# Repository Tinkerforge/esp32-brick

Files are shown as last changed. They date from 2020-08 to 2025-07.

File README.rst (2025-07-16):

ESP32 Brick
===========

This repository contains the firmware source code and the hardware design
files. The documentation generator configs can be found at
https://github.com/Tinkerforge/generators

Repository Overview
-------------------

.. DO NOT EDIT THIS OVERVIEW MANUALLY! CHANGE https://github.com/Tinkerforge/esp32-firmware/repo_overview.rst AND COPY THAT BLOCK INTO ALL REPOS LISTED BELOW. TODO: AUTOMATE THIS

Software
~~~~~~~~
- `esp32-firmware <https://github.com/Tinkerforge/esp32-firmware>`__  **Please report any issues concerning WARP hard- and software here!** Source code of the ESP32 firmware shared between all WARP Chargers and Energy Managers

- `tfjson <https://github.com/Tinkerforge/tfjson>`__ SAX style JSON serializer and deserializer
- `tfmodbustcp <https://github.com/Tinkerforge/tfmodbustcp>`__ Modbus TCP server and client implementation
- `tfocpp <https://github.com/Tinkerforge/tfocpp>`__ OCPP 1.6 implementation
- `tftools <https://github.com/Tinkerforge/tftools>`__ Miscellaneous tools and helpers

- `esp32-remote-access <https://github.com/Tinkerforge/esp32-remote-access>`__ Source code of the my.warp-charger.com remote access server

- `warp-charger <https://github.com/Tinkerforge/warp-charger>`__ The source code of (docs.)warp-charger.com and the printed manual, released firmwares, datasheets and documents, as well as some tools and hardware design files
- `api.warp-charger.com <https://github.com/Tinkerforge/api.warp-charger.com>`__ Serves APIs that are used by WARP Chargers to obtain relevant public information like day ahead prices
- `vislog.warp-charger.com <https://github.com/Tinkerforge/vislog.warp-charger.com>`__ Visualizes WARP Charger logs and EVSE debug protocols
- `dbus-warp-charger <https://github.com/Tinkerforge/dbus-warp-charger>`__ Integrates WARP Chargers into a Victron Energy Venus OS device (e.g. Cerbo GX)

WARP Charger Hardware
~~~~~~~~~~~~~~~~~~~~~~

- `esp32-brick <https://github.com/Tinkerforge/esp32-brick>`__ Hardware design files of the ESP32 Brick
- `evse-bricklet <https://github.com/Tinkerforge/evse-bricklet>`__  Firmware source code and hardware design files of the EVSE Bricklet
- `rs485-bricklet <https://github.com/Tinkerforge/rs485-bricklet>`__ Firmware source code and hardware design files of the RS485 Bricklet

WARP2 Charger Hardware
~~~~~~~~~~~~~~~~~~~~~~

- `esp32-ethernet-brick <https://github.com/Tinkerforge/esp32-ethernet-brick>`__ Hardware design files of the ESP32 Ethernet Brick
- `evse-v2-bricklet <https://github.com/Tinkerforge/evse-v2-bricklet>`__ Firmware source code and hardware design files of the EVSE 2.0 Bricklet
- `nfc-bricklet <https://github.com/Tinkerforge/nfc-bricklet>`__ Firmware source code and hardware design files of the NFC Bricklet

WARP3 Charger Hardware
~~~~~~~~~~~~~~~~~~~~~~

- `warp-esp32-ethernet-brick <https://github.com/Tinkerforge/warp-esp32-ethernet-brick>`__ Hardware design files of the WARP ESP32 Ethernet Brick
- `evse-v3-bricklet <https://github.com/Tinkerforge/evse-v3-bricklet>`__ Firmware source code and hardware design files of the EVSE 3.0 Bricklet
- `nfc-bricklet <https://github.com/Tinkerforge/nfc-bricklet>`__ Firmware source code and hardware design files of the NFC Bricklet

WARP Energy Manager Hardware
~~~~~~~~~~~~~~~~~~~~~~~~~~~~

- `esp32-ethernet-brick <https://github.com/Tinkerforge/esp32-ethernet-brick>`__ Hardware design files of the ESP32 Ethernet Brick
- `warp-energy-manager-bricklet <https://github.com/Tinkerforge/warp-energy-manager-bricklet>`__ Firmware source code and hardware design files of the WARP Energy Manager Bricklet

WARP Energy Manager 2.0 Hardware
~~~~~~~~~~~~~~~~~~~~~~~~~~~~~~~~

- `esp32-ethernet-brick <https://github.com/Tinkerforge/esp32-ethernet-brick>`__ Hardware design files of the ESP32 Ethernet Brick
- `warp-energy-manager-v2-bricklet <https://github.com/Tinkerforge/warp-energy-manager-v2-bricklet>`__ Firmware source code and hardware design files of the WARP Energy Manager 2.0 Bricklet
- `warp-front-panel-bricklet <https://github.com/Tinkerforge/warp-front-panel-bricklet>`__ Firmware source code and hardware design files of the WARP Front Panel Bricklet

Forked/patched projects
~~~~~~~~~~~~~~~~~~~~~~~

- `arduino-esp32 <https://github.com/Tinkerforge/arduino-esp32>`__
- `esp32-arduino-libs <https://github.com/Tinkerforge/esp32-arduino-libs>`__
- `WireGuard-ESP32-Arduino <https://github.com/Tinkerforge/WireGuard-ESP32-Arduino>`__

Repository Content
------------------

software/:
 * examples/: Examples for all supported languages
 * build/: Compiled files
 * src/: Source code of firmware
 * Makefile: Makefile to build project

hardware/:
 * Contains KiCad project files and additionally schematics as PDF

datasheets/:
 * Contains datasheets for sensors and complex ICs that are used

Hardware
--------

The hardware is designed with the open source EDA Suite KiCad
(http://www.kicad.org). Before you are able to open the files,
you have to install the Tinkerforge kicad-libraries
(https://github.com/Tinkerforge/kicad-libraries). You can either clone
them directly in hardware/ or clone them in a separate folder and
symlink them into hardware/
(ln -s kicad_path/kicad-libraries project_path/hardware). After that you
can open the .pro file in hardware/ with KiCad and from there view and
modify the schematics and the PCB layout.

Software
--------

See README.txt in the software folder for details.

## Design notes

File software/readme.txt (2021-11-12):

The content of this directory was merged into

https://github.com/Tinkerforge/esp32-firmware/tree/master/software

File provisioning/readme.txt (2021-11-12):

The content of this directory was moved to

https://github.com/Tinkerforge/esp32-firmware/tree/master/provisioning

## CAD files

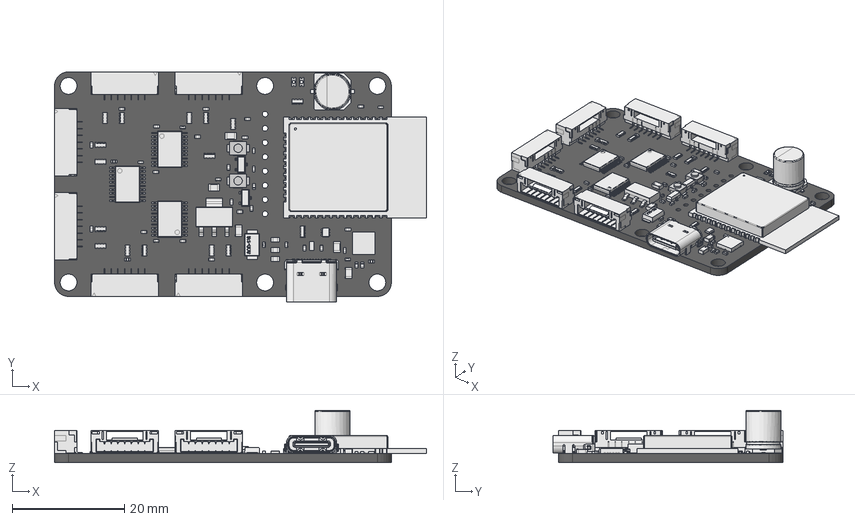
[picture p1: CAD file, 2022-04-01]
hardware/esp32.FCStd
66.2 x 41.0 x 9.30 mm
Pcb_7dfd
ESP32-WROOM-32
ESP32-WROOM-033
ESP32-WROOM-034
ESP32-WROOM-035
ESP32-WROOM-036
ESP32-WROOM-037
ESP32-WROOM-038
ESP32-WROOM-039
ESP32-WROOM-040
ESP32-WROOM-041
ESP32-WROOM-042
ESP32-WROOM-043
ESP32-WROOM-044
ESP32-WROOM-045
ESP32-WROOM-046
ESP32-WROOM-047
ESP32-WROOM-048
ESP32-WROOM-049
ESP32-WROOM-050
ESP32-WROOM-051
ESP32-WROOM-052
ESP32-WROOM-053
ESP32-WROOM-054
ESP32-WROOM-055
ESP32-WROOM-056
ESP32-WROOM-057
ESP32-WROOM-058
ESP32-WROOM-059
ESP32-WROOM-060
ESP32-WROOM-061
ESP32-WROOM-062
ESP32-WROOM-063
ESP32-WROOM-064
ESP32-WROOM-065
ESP32-WROOM-066
ESP32-WROOM-067
ESP32-WROOM-068
ESP32-WROOM-069
ESP32-WROOM-070
ESP32-WROOM-071
ESP32-WROOM-072
C112_C_0805_5F5B4DA2 x 5
SW101_B3U_1000P[]_5F5B68B4 x 2
Q102_SOT23_5E999EC0 x 2
RP104_Cut_5E9D7D33 x 16
U203_TSSOP-20_5E99A0A3 x 3
R202_R_0402_5E999F6A x 26
P206_BrickletConn_7pin_5E9D989A x 6
L104_R_0603_5E999E38 x 3
USB4105
USB4106
U103_QFN-24_4x4mm_Pitch0.5mm_5E99F04F
C101_C_0402_5E99F739 x 11
c_el_D8_D63_L77

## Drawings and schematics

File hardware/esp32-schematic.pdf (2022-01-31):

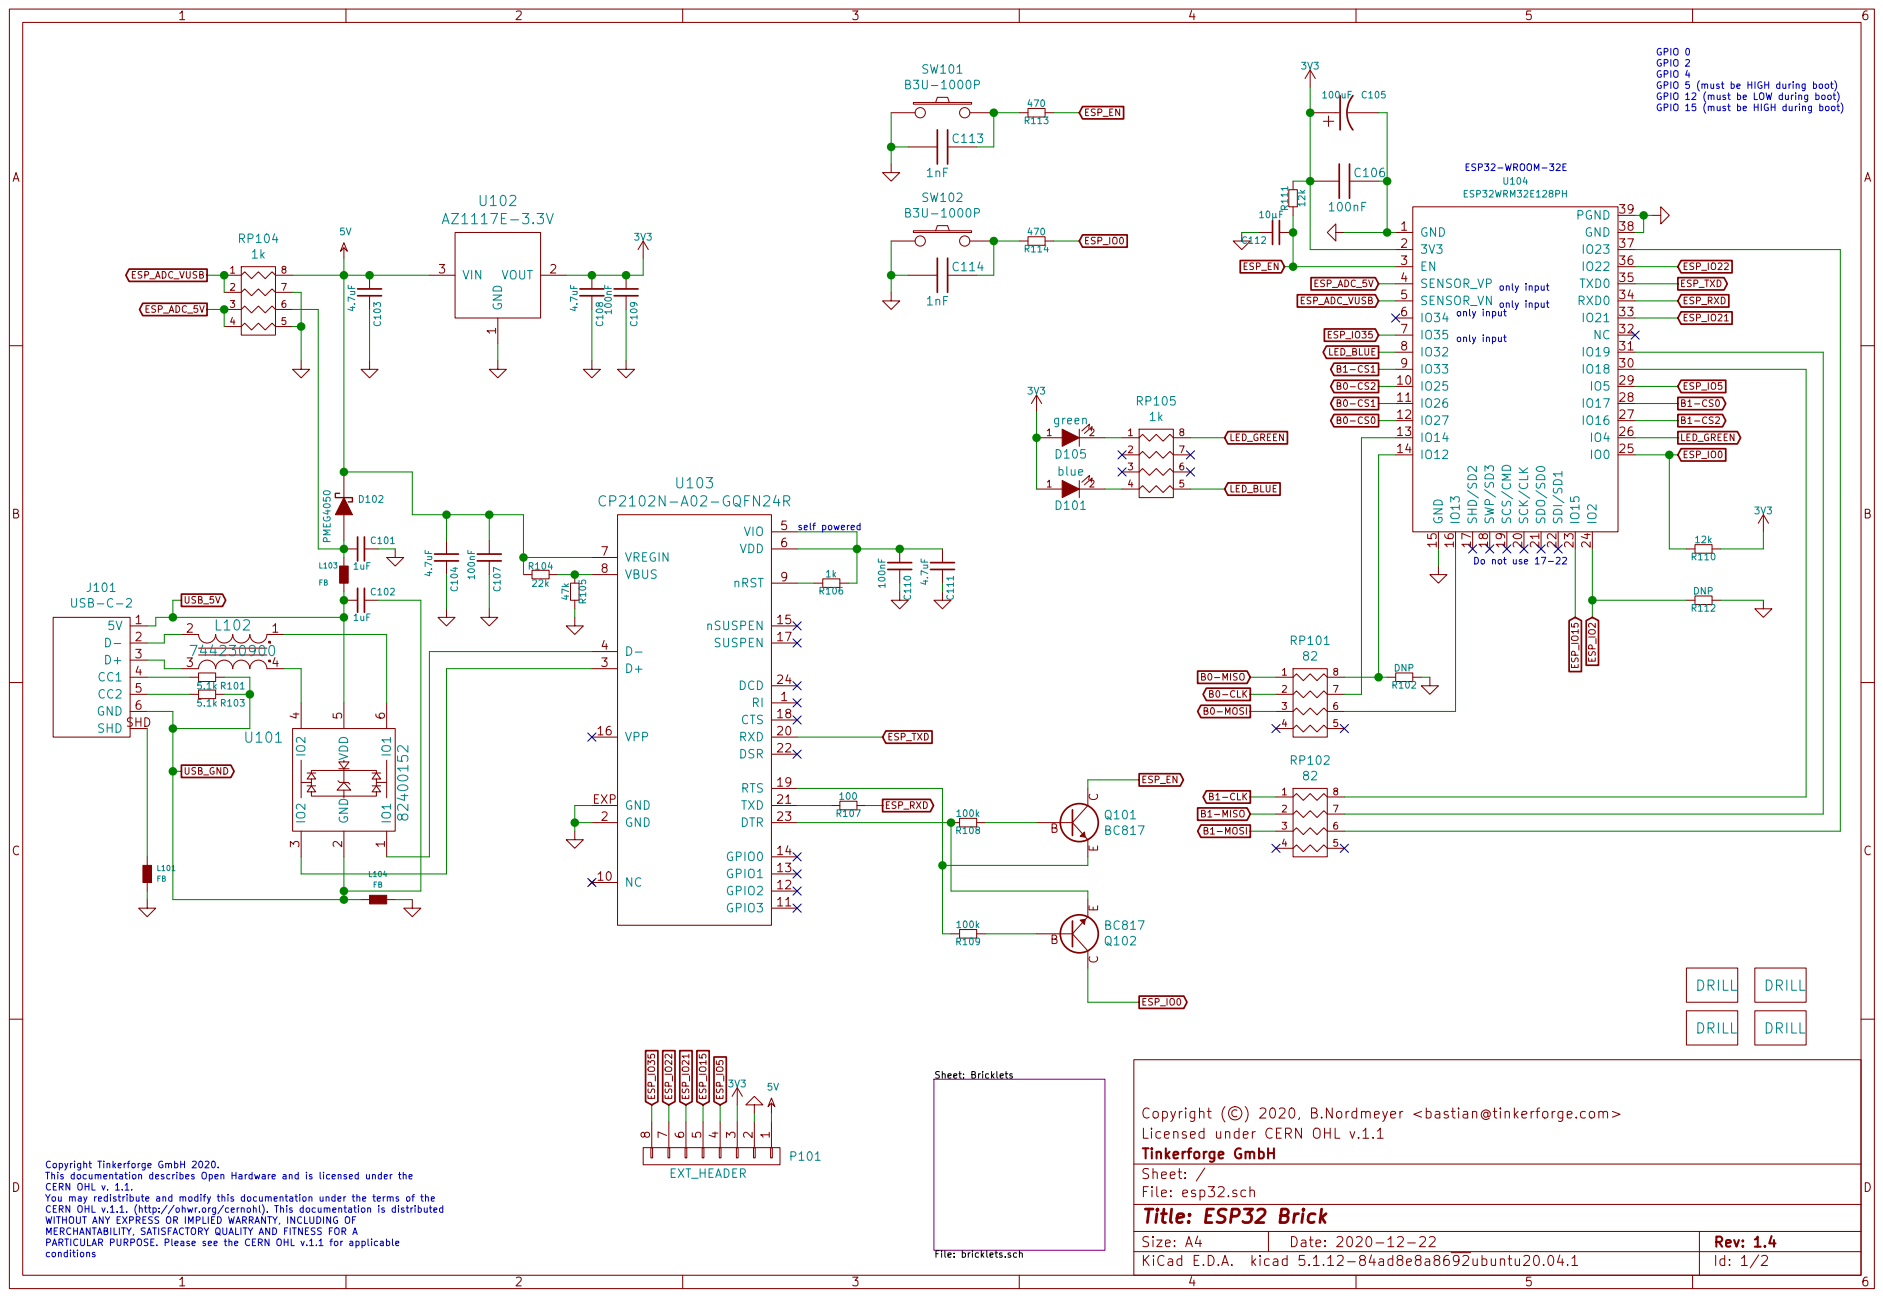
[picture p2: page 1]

GPIO 0
GPIO 2
GPIO 4
GPIO 5 (must be HIGH during boot)
GPIO 12 (must be LOW during boot)

GPIO 15 (must be HIGH during boot) only input only input only input only input Do not use 17-22 ESP32-WROOM-32E

self powered Copyright Tinkerforge GmbH 2020. This documentation describes Open Hardware and is licensed under the CERN OHL v. 1.1. You may redistribute and modify this documentation under the terms of the CERN OHL v.1.1. (http://ohwr.org/cernohl). This documentation is distributed WITHOUT ANY EXPRESS OR IMPLIED WARRANTY, INCLUDING OF MERCHANTABILITY, SATISFACTORY QUALITY AND FITNESS FOR A

Sheet: Bricklets File: bricklets.sch

Licensed under CERN OHL v.1.1 Copyright (©) 2020, B.Nordmeyer <bastian@tinkerforge.com>

File: esp32.sch Sheet: / Tinkerforge GmbH

PARTICULAR PURPOSE. Please see the CERN OHL v.1.1 for applicable
conditions

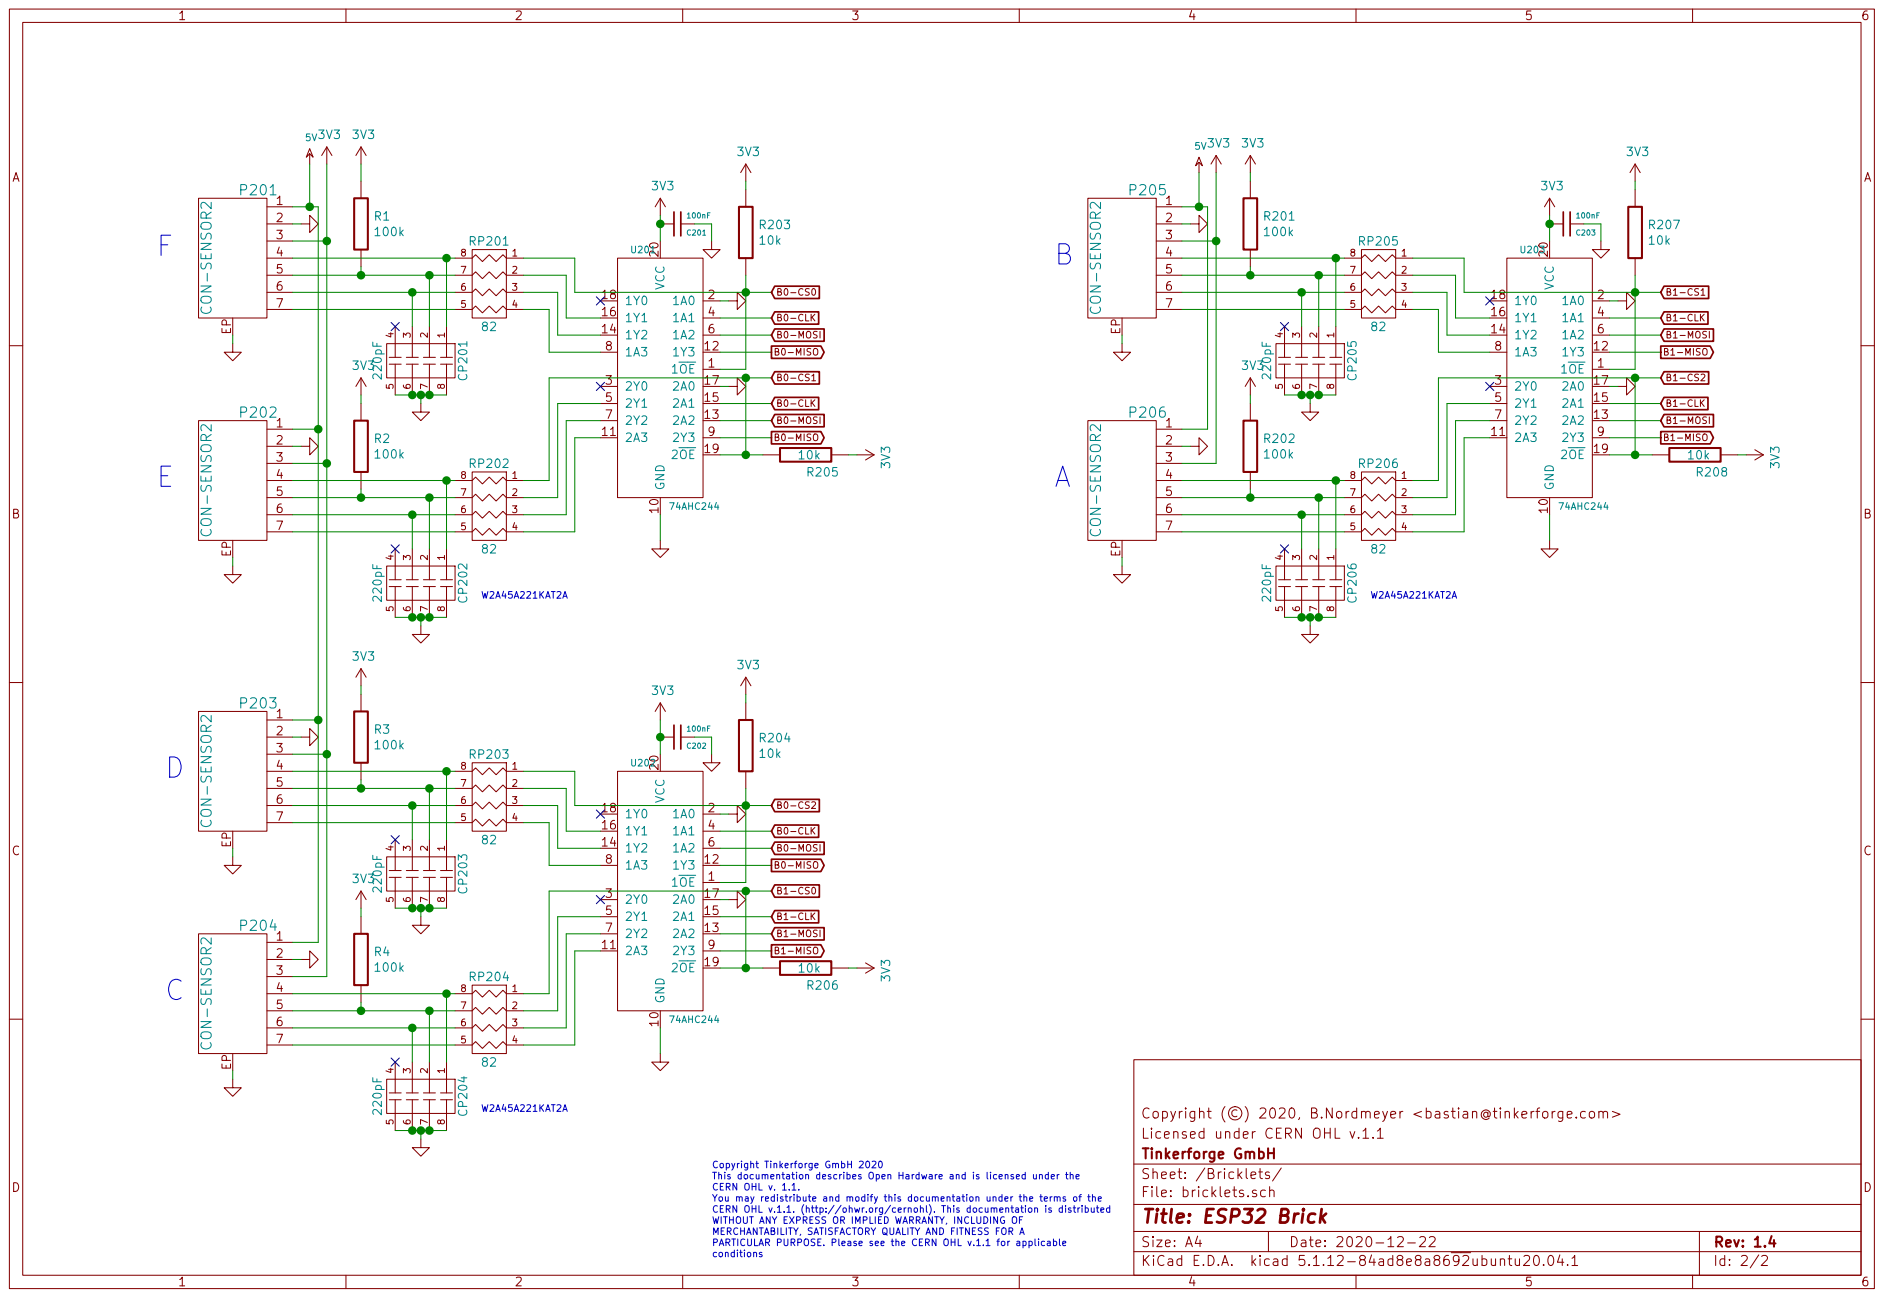
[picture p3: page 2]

Licensed under CERN OHL v.1.1 Copyright (©) 2020, B.Nordmeyer <bastian@tinkerforge.com> R4

File: bricklets.sch Sheet: /Bricklets/ Tinkerforge GmbH

PARTICULAR PURPOSE. Please see the CERN OHL v.1.1 for applicable

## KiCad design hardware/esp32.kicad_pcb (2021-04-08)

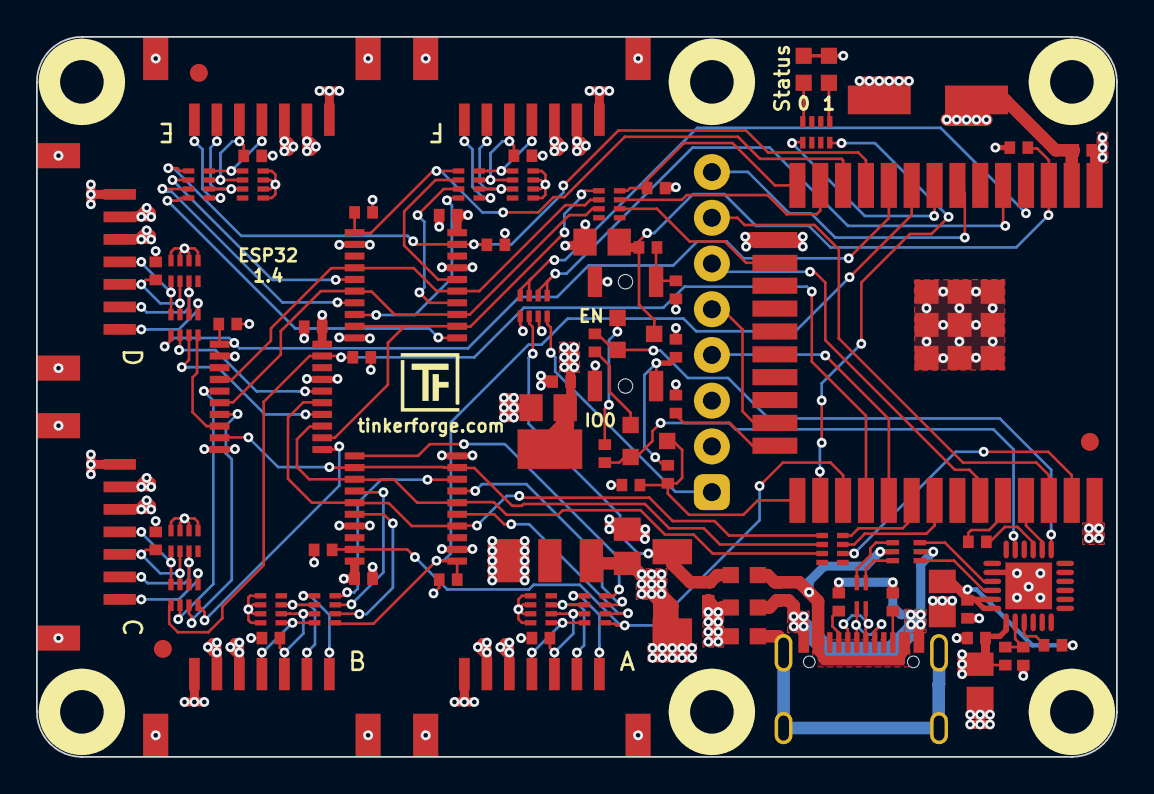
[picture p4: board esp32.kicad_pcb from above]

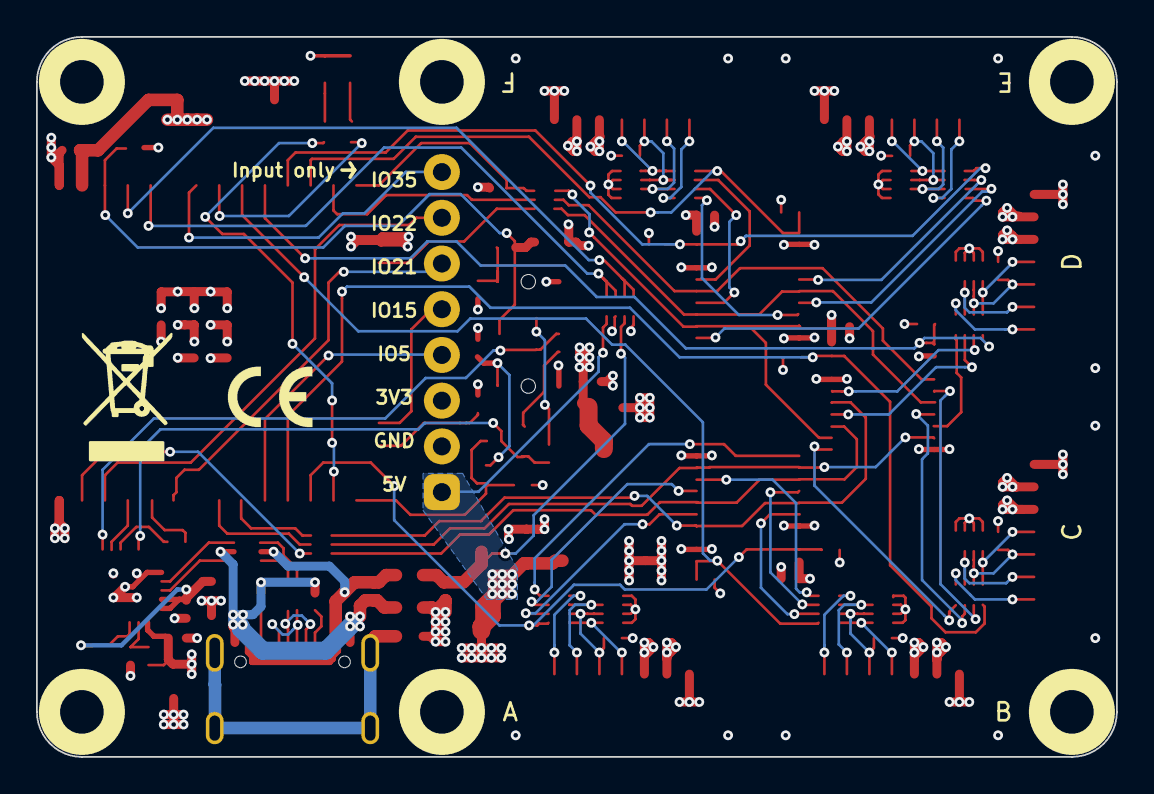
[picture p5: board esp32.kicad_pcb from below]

Board: 4 copper layers, 60.0 x 40.0 mm, 94 parts (2 on the bottom side), 101 nets.

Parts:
C101, C102: 1uF; C0402F
C103, C104, C108, C111: 4.7uF; C0805E
C105: 100uF; ELKO_63
C106, C107, C109, C110, C201, C202, C203: 100nF; C0402F
C112: 10µF; C0805E
C113, C114: 1nF; C0402F
CP201, CP202, CP203, CP204, CP205, CP206: 220pF; 4X0402
D101: blue; D0603F
D102: PMEG4050; SOD-128
D105: green; D0603F
F101, F102, F103, F104: DRILL; DRILL_NP
Fiducial_Mark: VAL**; Fiducial_Mark
Fiducial_Mark#2, Fiducial_Mark#3: VAL**; Fiducial_Mark
J101: USB-C-2
L101, L103, L104: FB; R0603F
L102: 744230900; WE-CNSW-0603
P101: EXT_HEADER; pin_array_1x8-P2mm_D1mm
P201, P202, P203, P204, P205, P206: CON-SENSOR2
Q101, Q102: BC817; SOT23EBC
R1, R2, R3, R4, R108, R109, R201, R202: 100k; R0402F
R101, R103: 5.1k; R0402F
R102, R112: DNP; R0402F
R104: 22k; R0402F
R105: 47k; R0402F
R106: 1k; R0402F
R107: 100; R0402F
R110, R111: 12k; R0402F
R113, R114: 470; R0402F
R203, R204, R205, R206, R207, R208: 10k; R0402F
RP101, RP102, RP201, RP202, RP203, RP204, RP205, RP206: 82; 4X0402
RP104, RP105: 1k; 4X0402
SW101, SW102: B3U-1000P
U101: 82400152; SOT563-SPEC
U102: AZ1117E-3.3V; SOT-223
U103: CP2102N-A02-GQFN24R; QFN24-4x4mm-0.5mm
U104: ESP32WRM32E128PH; ESP32-WROOM-32
U201, U202, U203: 74AHC244; TSSOP20
VAL: WEEE_7mm
VAL#2: CE_5mm

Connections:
3V3: C105.1, C106.2, C108.2, C109.2, C201.2, C202.2, C203.2, D101.1, D105.1, P101.3, P201.3, P202.3, P203.3, P204.3, P205.3, P206.3, R1.1, R2.1, R3.1, R4.1, R110.2, R111.1, R201.1, R202.1, R203.1, R204.1, R205.1, R206.1, R207.1, R208.1, U102.2, U104.2, U201.20, U202.20, U203.20
5V: C103.2, C104.2, C107.2, D102.2, P101.1, P201.1, P202.1, P203.1, P204.1, P205.1, P206.1, R104.2, RP104.8, U102.3, U103.7
B0-CLK: RP101.2, U201.4, U201.15, U202.4
B0-CS0: R203.2, RP201.1, U104.12, U201.1
B0-CS1: R205.2, RP202.1, U104.11, U201.19
B0-CS2: R204.2, RP203.1, U104.10, U202.1
B0-MISO: RP101.1, U201.9, U201.12, U202.12
B0-MOSI: RP101.3, U201.6, U201.13, U202.6
B1-CLK: RP102.1, U202.15, U203.4, U203.15
B1-CS0: R206.2, RP204.1, U104.28, U202.19
B1-CS1: R207.2, RP205.1, U104.9, U203.1
B1-CS2: R208.2, RP206.1, U104.27, U203.19
B1-MISO: RP102.2, U202.9, U203.9, U203.12
B1-MOSI: RP102.3, U202.13, U203.6, U203.13
ESP_ADC_5V: RP104.3, RP104.4, U104.4
ESP_ADC_VUSB: RP104.1, RP104.2, U104.5
ESP_EN: C112.2, Q101.C, R111.2, R113.2, U104.3
ESP_IO0: Q102.C, R110.1, R114.2, U104.25
ESP_IO2: R112.1, U104.24
ESP_IO5: P101.4, U104.29
ESP_IO15: P101.5, U104.23
ESP_IO21: P101.6, U104.33
ESP_IO22: P101.7, U104.36
ESP_IO35: P101.8, U104.7
ESP_RXD: R107.2, U104.34
ESP_TXD: U103.20, U104.35
GND: C101.1, C103.1, C104.1, C105.2, C106.1, C107.1, C108.1, C109.1, C110.1, C111.1, C112.1, C113.2, C114.2, C201.1, C202.1, C203.1, CP201.5, CP201.6, CP201.7, CP201.8, CP202.5, CP202.6, CP202.7, CP202.8, CP203.5, CP203.6, CP203.7, CP203.8, CP204.5, CP204.6, CP204.7, CP204.8, CP205.5, CP205.6, CP205.7, CP205.8, CP206.5, CP206.6, CP206.7, CP206.8, L101.1, L104.2, P101.2, P201.2, P201.EP, P202.2, P202.EP, P203.2, P203.EP, P204.2, P204.EP, P205.2, P205.EP, P206.2, P206.EP, R102.2, R105.1, R112.2, RP104.5, RP104.7, SW101.1, SW102.1, U102.1, U103.2, U103.EXP, U104.1, U104.15, U104.38, U104.39, U201.2, U201.10, U201.17, U202.2, U202.10, U202.17, U203.2, U203.10, U203.17
LED_BLUE: RP105.5, U104.8
LED_GREEN: RP105.8, U104.26
unnamed: C101.2, D102.1, L103.2, RP104.6
unnamed: C110.2, C111.2, R106.2, U103.5, U103.6
unnamed: C113.1, R113.1, SW101.2
unnamed: C114.1, R114.1, SW102.2
unnamed: CP201.1, P201.4, RP201.8
unnamed: CP201.2, P201.5, R1.2, RP201.7
unnamed: CP201.3, P201.6, RP201.6
unnamed: CP202.1, P202.4, RP202.8
unnamed: CP202.2, P202.5, R2.2, RP202.7
unnamed: CP202.3, P202.6, RP202.6
unnamed: CP203.1, P203.4, RP203.8
unnamed: CP203.2, P203.5, R3.2, RP203.7
unnamed: CP203.3, P203.6, RP203.6
unnamed: CP204.1, P204.4, RP204.8
unnamed: CP204.2, P204.5, R4.2, RP204.7
unnamed: CP204.3, P204.6, RP204.6
unnamed: CP205.1, P205.4, RP205.8
unnamed: CP205.2, P205.5, R201.2, RP205.7
unnamed: CP205.3, P205.6, RP205.6
unnamed: CP206.1, P206.4, RP206.8
unnamed: CP206.2, P206.5, R202.2, RP206.7
unnamed: CP206.3, P206.6, RP206.6
unnamed: D101.2, RP105.4
unnamed: D105.2, RP105.1
unnamed: J101.2, L102.2
unnamed: J101.3, L102.3
unnamed: J101.4, R101.2
unnamed: J101.5, R103.2
unnamed: J101.SHD, L101.2
unnamed: L102.1, U101.6
unnamed: L102.4, U101.4
unnamed: P201.7, RP201.5
unnamed: P202.7, RP202.5
unnamed: P203.7, RP203.5
unnamed: P204.7, RP204.5
unnamed: P205.7, RP205.5
unnamed: P206.7, RP206.5
unnamed: Q101.B, R108.2
unnamed: Q101.E, R109.1, U103.19
unnamed: Q102.B, R109.2
unnamed: Q102.E, R108.1, U103.23
unnamed: R102.1, RP101.8, U104.14
unnamed: R104.1, R105.2, U103.8
unnamed: R106.1, U103.9
unnamed: R107.1, U103.21
unnamed: RP101.6, U104.16
unnamed: RP101.7, U104.13
unnamed: RP102.6, U104.37
unnamed: RP102.7, U104.31
unnamed: RP102.8, U104.30
unnamed: RP201.2, U201.16
unnamed: RP201.3, U201.14
unnamed: RP201.4, U201.8
unnamed: RP202.2, U201.5
unnamed: RP202.3, U201.7
unnamed: RP202.4, U201.11
unnamed: RP203.2, U202.16
unnamed: RP203.3, U202.14
unnamed: RP203.4, U202.8
unnamed: RP204.2, U202.5
unnamed: RP204.3, U202.7
unnamed: RP204.4, U202.11
unnamed: RP205.2, U203.16
unnamed: RP205.3, U203.14
unnamed: RP205.4, U203.8
unnamed: RP206.2, U203.5
unnamed: RP206.3, U203.7
unnamed: RP206.4, U203.11
unnamed: U101.1, U103.4
unnamed: U101.3, U103.3
USB_5V: C102.2, J101.1, L103.1, U101.5
USB_GND: C102.1, J101.6, L104.1, R101.1, R103.1, U101.2

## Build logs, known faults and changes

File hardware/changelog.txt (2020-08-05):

Version 1.1: Add extension header, fix NPN bug, change LED signals
Version 1.0: Initial

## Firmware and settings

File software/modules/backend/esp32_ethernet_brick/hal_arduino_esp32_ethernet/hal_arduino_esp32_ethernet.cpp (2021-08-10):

/*
 * Copyright (C) 2020 Erik Fleckstein <erik@tinkerforge.com>
 *
 * Redistribution and use in source and binary forms of this file,
 * with or without modification, are permitted. See the Creative
 * Commons Zero (CC0 1.0) License for more details.
 */

#include "hal_arduino_esp32_ethernet.h"
#include "SPI.h"
#include <Arduino.h>

#include "bindings/config.h"
#include "bindings/errors.h"

static const int CS_PIN_0 = 12;
static const int CS_PIN_1 = 13;
static const int CS_PIN_2 = 14;
static const int CLK_PIN = 32;
static const int MOSI_PIN = 33;
static const int MISO_PIN = 35;

void select_demux(uint8_t port_id) {
    // As we always alternate between select_demux and deselect_demux, we can assume, that all three pins are high.
    // clearing the pins we want to set to 0 is sufficient.

    //invert to use the W1TC (write 1 to clear) register
    uint8_t inv = ~port_id;
    REG_WRITE(GPIO_OUT_W1TC_REG, (inv & 0x07) << CS_PIN_0);
}

void deselect_demux() {
    REG_WRITE(GPIO_OUT_W1TS_REG, 0x07 << CS_PIN_0);
}

int tf_hal_create(TF_HalContext *hal, TF_Port *ports, uint8_t port_count) {
    int rc = tf_hal_common_create(hal);
    if (rc != TF_E_OK) {
        return rc;
    }

    hal->ports = ports;
    hal->port_count = port_count;

    hal->spi_settings = SPISettings(1400000, SPI_MSBFIRST, SPI_MODE3);

    hal->hspi = SPIClass(HSPI);
    hal->hspi.begin(CLK_PIN, MISO_PIN, MOSI_PIN);

    pinMode(CS_PIN_0, OUTPUT);
    pinMode(CS_PIN_1, OUTPUT);
    pinMode(CS_PIN_2, OUTPUT);
    deselect_demux();

    return tf_hal_common_prepare(hal, port_count, 50000);
}

int tf_hal_destroy(TF_HalContext *hal){
    hal->hspi.end();
    return TF_E_OK;
}

int tf_hal_chip_select(TF_HalContext *hal, uint8_t port_id, bool enable){
    if (enable) {
        hal->hspi.beginTransaction(hal->spi_settings);
        select_demux(port_id);
    } else {
        deselect_demux();
        hal->hspi.endTransaction();
    }
    return TF_E_OK;
}

int tf_hal_transceive(TF_HalContext *hal, uint8_t port_id, const uint8_t *write_buffer, uint8_t *read_buffer, uint32_t length){
    memcpy(read_buffer, write_buffer, length);
    hal->hspi.transfer(read_buffer, length);
    return TF_E_OK;
}

uint32_t tf_hal_current_time_us(TF_HalContext *hal){
    return micros();
}

void tf_hal_sleep_us(TF_HalContext *hal, uint32_t us) {
    while(us > 16000) {
        delay(16);
        us -= 16000;
    }
    delayMicroseconds(us);
}

TF_HalCommon *tf_hal_get_common(TF_HalContext *hal) {
    return &hal->hal_common;
}

void tf_hal_log_message(const char *msg, size_t len) {
    Serial.write((const uint8_t *) msg, len);
}

void tf_hal_log_newline() {
    Serial.println("");
}

#ifdef TF_IMPLEMENT_STRERROR
const char *tf_hal_strerror(int e_code) {
    switch(e_code) {
        #include "bindings/error_cases.h"
        default:
            return "unknown error";
    }
}
#endif

char tf_hal_get_port_name(TF_HalContext *hal, uint8_t port_id) {
    if(port_id > hal->port_count)
        return '?';
    return hal->ports[port_id].port_name;
}

TF_PortCommon *tf_hal_get_port_common(TF_HalContext *hal, uint8_t port_id) {
    if(port_id > hal->port_count)
        return NULL;
    return &hal->ports[port_id].port_common;
}

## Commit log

2020-04-17 add first parts of schematic and board
    [bricklets.sch, esp32.kicad_pcb, esp32.sch]
2020-04-20 routing finished
    [bricklets.sch, esp32.kicad_pcb, esp32.sch]
2020-04-20 version 1.0 finished
    [esp32.kicad_pcb, esp32.sch]
2020-04-24 specify diodes
    [esp32.kicad_pcb, esp32.sch]
2020-04-29 fix header silkscreen
    [esp32.kicad_pcb]
2020-05-20 define parts
    [esp32.kicad_pcb, esp32.sch]
2020-05-20 bugfix flash circuitry
    [esp32.kicad_pcb, esp32.sch]
2020-07-07 fix esp32
    [esp32.kicad_pcb, esp32.sch]
2020-08-04 esp brick version 1.1
    changed power input connector 2 pole
    fix npn cricuitry
    [esp32.kicad_pcb, esp32.sch]
2020-08-05 add larger header
    [esp32.kicad_pcb, esp32.sch]
2020-08-06 add power supply module
    [esp32-pwr.kicad_pcb, esp32-pwr.sch]
2020-08-06 switch from 4 layer design to 2 layer
    [esp32-pwr.kicad_pcb]
2020-08-06 ordered prototype version 1.1
    [esp32.kicad_pcb]
2020-08-14 updated footprints drc
    [esp32-pwr.kicad_pcb]
2020-08-14 changed version number on silkscreen
    [esp32-pwr.kicad_pcb]
2020-08-25 version 1.2
    * fix usb-c cc resistors
    [bricklets.sch, esp32.kicad_pcb, esp32.sch]
2020-09-09 add bottom port text, drc
    [esp32.kicad_pcb]
2020-09-09 fix vcc layer
    [esp32.kicad_pcb]
2020-09-10 fix values
    [esp32.kicad_pcb, esp32.sch]
2020-09-10 hardware version 1.3
    * fix reset logic
    [bricklets.sch, esp32.kicad_pcb, esp32.sch]
2020-09-11 add push buttons
    [bricklets.sch, esp32.kicad_pcb, esp32.sch]
2020-09-11 move push buttons
    [bricklets.sch, esp32.kicad_pcb, esp32.sch]
2020-09-24 Changed values of R108 and R109 from 12k to 100k Changed value of R110 form 5k to 12k
    [bricklets.sch, esp32.kicad_pcb, esp32.sch]
2020-10-20 added step
    [esp32.kicad_pcb]
2020-10-20 added fcstd
    [esp32.fcstd]
2020-11-09 fix usb c footprint type
    [esp32.kicad_pcb]
2020-12-15 firmware_update: Add factory reset per web interface or IO0 button.
2020-12-22 add version 1.4
    * add CS 10k resistors to SPI
    * fix logo positions
    [bricklets.sch, esp32.kicad_pcb, esp32.sch]
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2021-01-13 Add label print script
2021-01-15 wifi: Stop soft AP only once. Print to serial.
2021-01-19 Fix label print script path.
2021-01-21 Add current date and time to debug report filename.
2021-01-29 wifi: Restore printing the STA IP on the serial console.
2021-02-01 api: Add connected devices to debug report.
2021-02-01 api: Fix race condition in onMqttConnect.
    onMqttConnect happens asynchronously to the
    "main thread" i.e. the one used by the task scheduler.
    This enabled a race condition between the MQTT publishing when
    a client (re)connects and the publishing when a state changes.
2021-02-03 fix port bottom descriptions
    [esp32.kicad_pcb]
2021-02-10 mqtt: Don't try to connect if Wifi is currently reconnecting.
2021-02-11 Use esp32-lib to build.
    [default_16MB_coredump.csv]
2021-02-16 provisioning: Fix printing of non-str values
2021-02-17 wifi: Fix MQTT never connecting when using static IPS.
    The MQTT module never connected to a broker if static IPs where used,
    because the WIFI module never sets the state to ::CONNECTED.
    For some reason SYSTEM_EVENT_STA_CONNECTED did not fire in this case,
    but instead SYSTEM_EVENT_STA_GOT_IP fired twice. This seems to be
    a known problem:
    https://github.com/espressif/arduino-esp32/issues/2856
    We now set the ::CONNECTED state also in the GOT_IP event to
    circumvent this.
2021-02-17 wifi: Fix passphrase print alignment.
2021-02-24 firmware_update: Add reboot button. Improve layout.
2021-03-02 provisioning: Check ESP fuses with QR code. Add install instructions.
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2021-03-12 authentication: Add custom login page. Remove logout button.
    Logging out a user by overwriting the cached credentials only works
    in Chrome up to version 78 and in Firefox. The cache is cleared when
    closing the browser window anyway, so this is unnecessary confusing.
2021-03-30 provisioning: Print ESP Brick QR code data
2021-04-01 provisioning: Add --stdout option to print script
2021-04-08 add somehow missing logos and fiducials
    [esp32.kicad_pcb]
2021-04-12 mqtt/wifi: Add clear password switch.
2021-04-16 fix bricklet port description
    [bricklets.sch]
2021-05-20 wifi: Port to arduino-esp 2.0 API.
2021-05-20 provisioning: Split into stage 0 and stage 1.
    Run stage 0 with
    parallel -j 9 -u python3 provision_stage_0.py [firmware] '{}' ::: /dev/ttyUSB*
    to flash up to nine ESPs in parallel. Then wait until the LEDs start
    blinking.
2021-05-28 Switch from printer hostname to IP address to avoid collision
2021-05-28 Mark stage 1 script as executable
2021-06-01 provisioning: Hard code static IP of label printer.
2021-06-07 wifi: Adapt to esp32-lib API changes.
2021-06-21 provisioning: Use hidden proxy mode for stage 2.
2021-06-25 provisioning: Enable hidden proxy in stage 1.
2021-07-02 provisioning: Write report before printing labels.
2021-07-19 debug: Only report byte accessable free heap.
    ESP.getFreeHeap() includes memory that can only be accessed with
    32 bit alignment. However malloc etc. will never allocate from this
    memory.
    https://github.com/espressif/arduino-esp32/issues/5346#issuecomment-872940393
2021-07-27 wifi: Remove hard dependency to web socket module.
2021-07-30 Add prototype of ethernet module.
    Ethernet works, but has no configuration or web interface plugin yet.
2021-07-30 ethernet/wifi: Port to arduino-esp 2.0 API.
2021-07-30 firmware_update: Disable IO0 button factory reset for now.
    The ethernet chip accidentally triggers a firmware update sometimes.
2021-08-10 Add board modules with HALs. Use for firmware update.
2021-08-10 esp32-brick: Restore LED blink. Fix compile errors.
    [hal_arduino_esp32.cpp]
2021-08-25 wifi: Don't switch off if AP is closed. Currently broken.
    Calling wifi.softAPdisconnect(true) prints
    E wifi_init_default: esp_wifi_get_mac failed with 12289
    This seems to be this issue:
    https://github.com/espressif/arduino-esp32/issues/5459
2021-09-01 firmware_update: Use information from firmware info page.
    See tinkerforge/warp-charger@362a1466 for details.
2021-09-01 hidden_proxy: Blink green status LED while running.
    This is primarily to check if the green LED is working while
    provisioning an ESP32 Ethernet Brick.
2021-09-07 Add initial stage 3 provisioning script
2021-09-08 wifi: Remove debug print.
2021-09-08 esp32_ethernet_brick: Remove factory reset.
    The IO0 button can not be read safely, as the ethernet clock is on
    the same pin.
    For WARP2 we instead use the wallbox button to trigger a factory reset
    when booting the ESP.
2021-09-08 provisioning: Don't assume USB cable is plugged.
2021-09-08 provisioning: Fix stage 2.
2021-09-08 privisioning: Switch to monoflop usage for safety
2021-09-08 provision: Run stage 2 in try except to show errors.
2021-09-08 provision: Ignore flash errors in stage 0. Add printer IP to stage 1.
2021-09-08 provisioning: Add done message to stage 2 script
2021-09-08 provisioning: Do a clean exit(0) if the printer is missing and the user aborts
    There's no point in reporting the full traceback in this case.
2021-09-08 provisioning/stage1: Fix infinite loop
2021-09-08 provisioning: Don't report full traceback for fatal_error calls
    The fatal error is already handled by the caller of the fatal_error
    function. Only report tracebacks for unhandled exceptions.
2021-09-09 provision: Open web interface when done with stage 1.
2021-09-09 provisioning: Remove IO0 button test.
2021-09-09 provisioning/stage3: Add meter helper functions
2021-09-10 provisioning/stage3: Add support for NFC and Color Bricklet
2021-09-10 provisioning/stage3: Add wallbox test function dummy
2021-09-10 provisioning/stage3: Add actual wallboxc test
2021-09-10 provisioning/stage3: Fix variable name
2021-09-10 provisioning/stage3: Print test steps
2021-09-10 provisioning/stage3: Add missing phase combination test
2021-09-10 provision: Use automated tester in stage 2.
2021-09-10 provisioning: Turn power on after all QR codes are scanned
    Otherwise scanning the 3rd QR code might be missed because turning
    on the power takes a moment.
2021-09-10 provisioning: Turn power off before exiting
    Instead of waiting for monoflops to drop.
2021-09-10 provisioning: Fix front panel button test logic
2021-09-13 provisioning/stage2: Blink for NFC tags.
2021-09-13 provisioning/stage2: Use selenium to open web interface.
2021-09-13 provisioning: Add more prints to wallbox test
2021-09-13 provisioning: Force exit on action thread error
2021-09-13 provisioning: Fine tune voltage measurement
2021-09-13 provisioning: Fix order of some prints
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2021-09-14 provisioning/stage2: Close browser on error.
2021-09-14 provisioning: Wait for integration time after releasing the button
2021-09-14 provisioning: Reorder some prints
2021-09-15 provisioning: Include electrical tests result in stage 2 report
2021-09-15 provisioning: Fix power-on logic for wallboxes with supply cable
2021-09-24 provisioning/stage3: Ensure that IEC states are stable
2021-09-28 provisioning/stage3: Retry up to 5 times on QR code reader error
2021-09-30 provisioning/stage3: Add beep indicator for success/failure
2021-09-30 provisioning/stage3: Fix and fine tune beeping
2021-10-06 provisioning/stage2: Improve meter error messages.
2021-10-12 ethernet: Fix module initialization. Fixes Tinkerforge/warp-charger#11.
2021-10-13 provisioning/stage1: Add timeout to reboot request.
2021-10-20 provisioning: Add GUI to stage 3 script
2021-10-20 provisioning/warp2: Switch from PyQt5 to tk
    To avoid strange conflict between OpenCV and PyQt5.
2021-10-20 provisioning/warp2: Add done print
2021-10-22 event_log: Merge download event log and debug report buttons.
2021-10-25 Update KiCad link
    https://www.kicad.org/blog/2021/10/Avoid-links-to-former-kicad-domain/
2021-10-29 mqtt: Add missing printf param.
2021-11-04 provisioning/stage2: Add hint why proxy connection could be failed.
2021-11-04 provisioning/stage2: Update firmware if outdated.
2021-11-04 provisioning/stage2: Also do a factory reset when reflashing.
2021-11-12 provision/stage2: Handle failed firmware update.
2021-11-12 provision/stage_2: Fix error handling.
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2021-11-12 Move software to esp32-firmware git
    [default_16MB_coredump.csv]
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2022-04-01 add 3d files
    [esp32.FCStd]
2022-04-01 cleanup, power supply got its own repository
    [esp32-pwr.kicad_pcb, esp32-pwr.sch]
